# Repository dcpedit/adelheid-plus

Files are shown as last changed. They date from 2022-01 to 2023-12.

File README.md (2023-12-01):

# 𝕬𝖉𝖊𝖑𝖍𝖊𝖎𝖉 Plus

The Adelheid Plus is a fork of [Flookay's Adelheid case and PCB](https://github.com/floookay/adelheid).

adelheid_plus_resized
*Photo by yosoyjose*

Repository folders:

- `pcb`: KiCad files
- `pcb-mu`: KiCad files for Atmega32u4-MU chip (same pinout as Atmega32u4-AU, but smaller footprint)
- `case`: High profile case files
- `wrist-rest`: Wrist rest files

I modifed the pcb a bit to accept an Atmega32u4-MU since those seem to be in stock more often.

## Changes in this fork

- USB-C connector
- Option for 2U backspace
- Extra `B` key
- Option for rotary encoder at `F13` position
- Option for 2.25U left space + 1.25U modifier combo (requires modification to plate)

## Layout

[Keyboard-Layout-Editor](http://www.keyboard-layout-editor.com/#/gists/57b8a9ee4aeb89308701e20eda9b5dfc) 
layout

## Firmware

See my Vial fork for the [firmware files](https://github.com/dcpedit/vial-qmk-dev/tree/dcpedit/keyboards/dcpedit/adelheid_plus) on the [`dcpedit` branch](https://github.com/dcpedit/vial-qmk-dev/tree/dcpedit).  I opted for Vial since it allows you to program the rotary encoder through their GUI: https://get.vial.today/

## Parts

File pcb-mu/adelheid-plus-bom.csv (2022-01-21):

Comment | Designator | Footprint | LCSC
22pF | C1,C2 | Capacitors_SMD:C_0805_HandSoldering | C1804
10uF | C3 | Capacitors_SMD:C_0805_HandSoldering | C15850
1uF (±10%) | C4 | Capacitors_SMD:C_0805_HandSoldering | C28323
1uF | C5 | Capacitors_SMD:C_0805_HandSoldering | C28323
0.1uF | C6,C7,C8,C9 | Capacitors_SMD:C_0805_HandSoldering | C49678
D | D1,D2,D3,D4,D5,D6,D7,D8,D9,D10,D11,D12,D13,D14,D15,D16,D17,D18,D19,D20,D21,D22,D23,D24,D25,D26,D27,D28,D29,D30,D31,D32,D33,D34,D35,D36,D37,D38,D39,D40,D41,D42,D43,D44,D45,D46,D47,D48,D49,D50,D51,D52,D53,D54,D55,D56,D57,D58,D59,D60,D61,D62,D63,D64,D65,D66,D67,D68,D69,D70,D71,D72,D73,D74,D75,D76,D77,D78,D79,D80,D81,D82,D34_1 | Diode_SMD:D_SOD-123 | C81598
LED | LS1,LS2,LS3,LS4,LS5,LS6,LS7,LS8,LS9,LS10,LS11,LS12,LS13,LS14,LS15,LS16,LS17 | LED_SMD:LED_0805_2012Metric_Pad1.15x1.40mm_HandSolder | C34499
2N7002 | Q1 | Package_TO_SOT_SMD:SOT-23 | C8545
22 | R1,R2 | Resistor_SMD:R_0805_2012Metric_Pad1.15x1.40mm_HandSolder | C17561
10K | R3,R4 | Resistor_SMD:R_0805_2012Metric_Pad1.15x1.40mm_HandSolder | C17414
1.5K | R5 | Resistor_SMD:R_0805_2012Metric_Pad1.15x1.40mm_HandSolder | C4310
R | RL1,RS1,RL2,RS2,RL3,RS3,RL4,RS4,RL5,RS5,RL6,RS6,RL7,RS7,RL8,RS8,RL9,RS9,RL10,RS10,RL11,RS11,RL12,RS12,RL13,RS13,RL14,RS14,RL15,RS15,RL16,RS16,RL17,RS17,RL18,RL19,RL20,RL21,RL22,RL23,RL24,RL25,RL26,RL27,RL28,RL29,RL30,RL31,RL32,RL33,RL34,RL35,RL36,RL37,RL38,RL39,RL40,RL41,RL42,RL43,RL44,RL45,RL46,RL47,RL48,RL49,RL50,RL51,RL52,RL53,RL54,RL55,RL56,RL57,RL58,RL59,RL60,RL61,RL62,RL63,RL64,RL65,RL66,RL67,RL68,RL69,RL70,RL71,RL72,RL73,RL74,RL75,RL76,RL77,RL78,RL79,RL80,RL81,RL82 | Resistor_SMD:R_0805_2012Metric_Pad1.15x1.40mm_HandSolder | C17798
R | RL34_1 | Resistor_SMD:R_0805_2012Metric_Pad1.20x1.40mm_HandSolder | C17798
5.1K | RU1,RU2 | Resistor_SMD:R_0805_2012Metric_Pad1.20x1.40mm_HandSolder | C27834
ATmega32U4-MU | U2 | adelheid:QFN50P700X700X100-45N | C112161
Crystal_GND24 | Y1 | Crystals:Crystal_SMD_SeikoEpson_FA238-4pin_3.2x2.5mm_HandSoldering | C13738

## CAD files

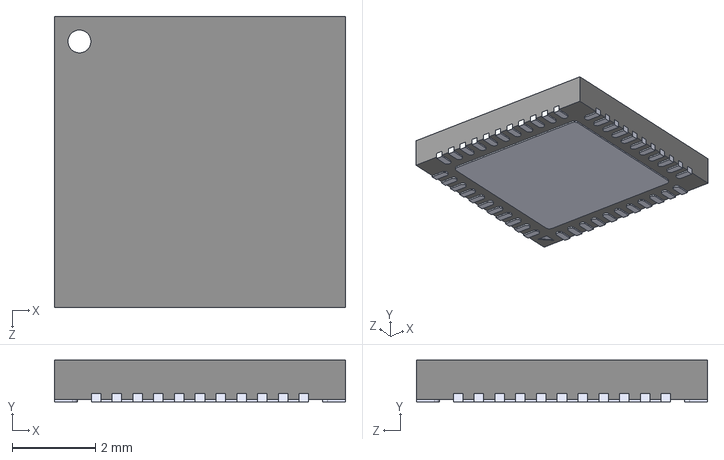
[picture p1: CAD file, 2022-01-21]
pcb-mu/ATMEGA32U4-MU.step
7.00 x 1.00 x 7.00 mm

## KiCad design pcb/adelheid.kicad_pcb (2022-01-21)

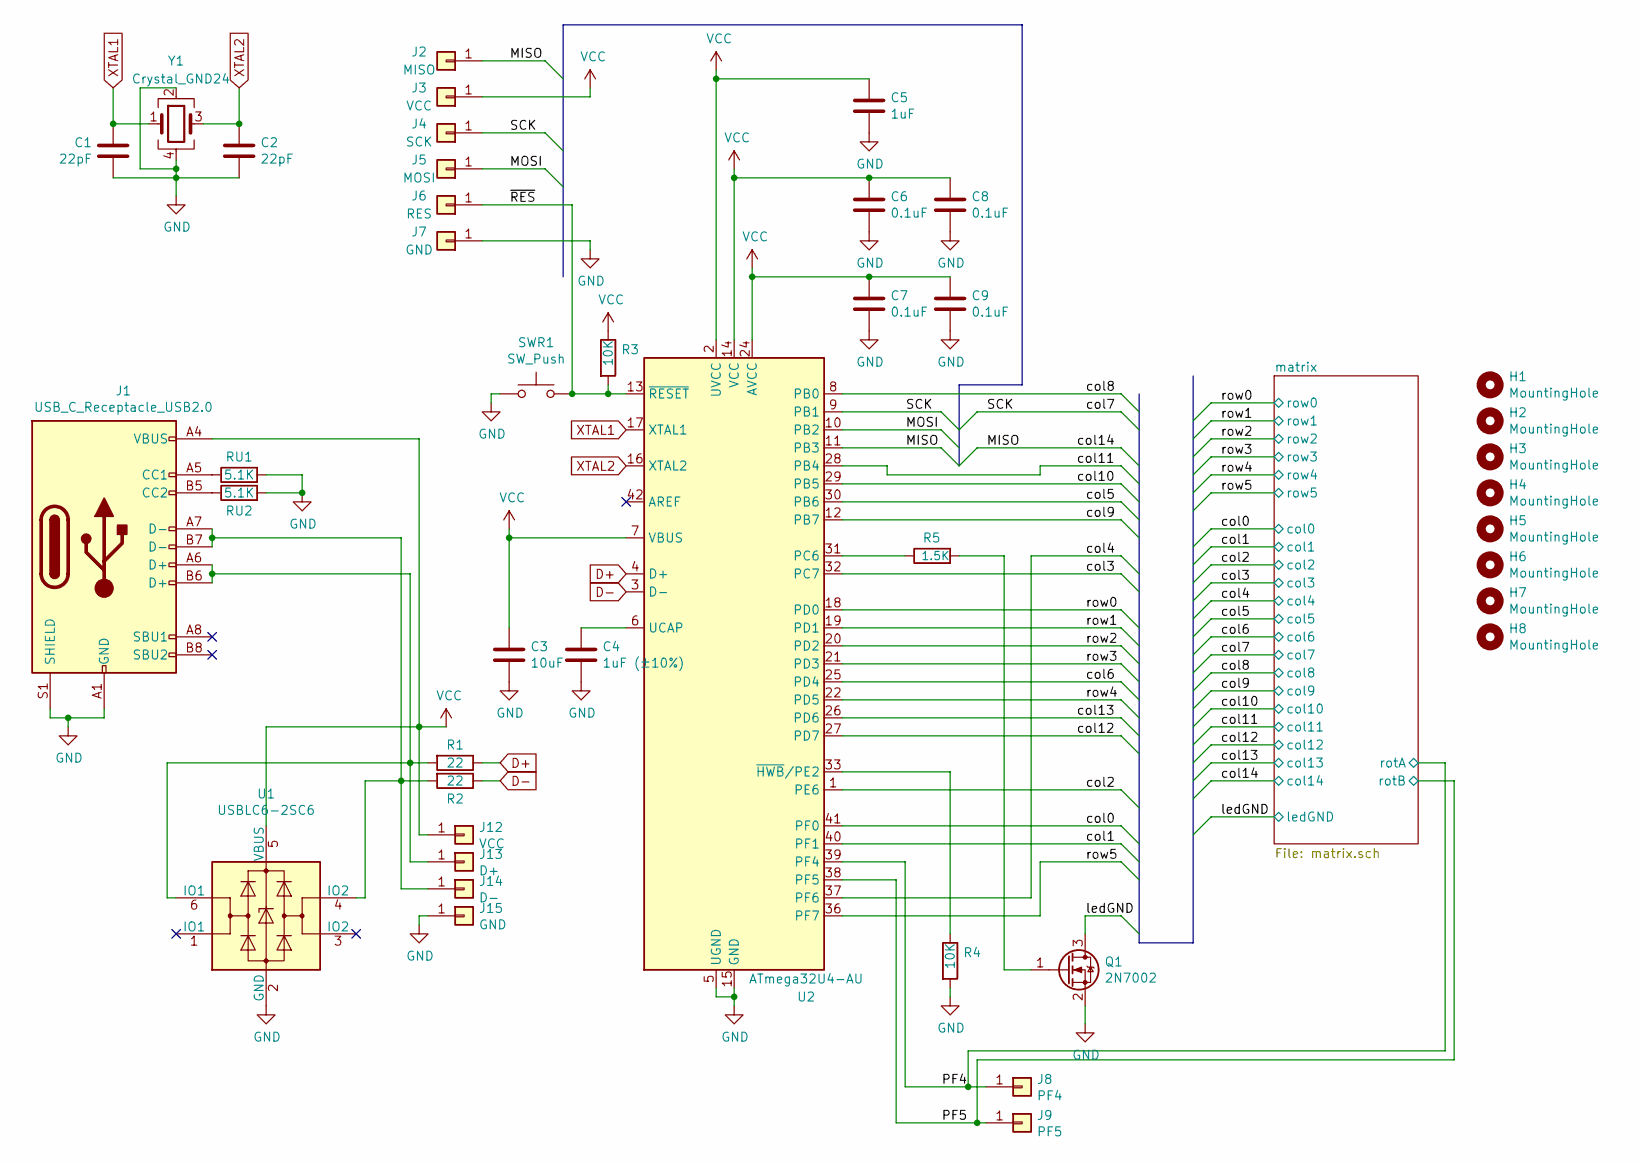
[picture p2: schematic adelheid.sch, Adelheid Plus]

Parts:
C1, C2: 22pF; C_0805_HandSoldering; LCSC C1804
C3: 10uF; C_0805_HandSoldering; LCSC C15850
C4: 1uF (±10%); C_0805_HandSoldering; LCSC C28323
C5: 1uF; C_0805_HandSoldering; LCSC C28323
C6, C7, C8, C9: 0.1uF; C_0805_HandSoldering; LCSC C49678
H1, H2, H3, H4, H5, H6, H7, H8: MountingHole; MountingHole_2.2mm_M2_Pad
J1: USB_C_Receptacle_USB2.0; USB_C_GCT_USB4085
J2: MISO; Pin_Header_Straight_1x01_Pitch2.54mm
J3, J12: VCC; Pin_Header_Straight_1x01_Pitch2.54mm
J4: SCK; Pin_Header_Straight_1x01_Pitch2.54mm
J5: MOSI; Pin_Header_Straight_1x01_Pitch2.54mm
J6: RES; Pin_Header_Straight_1x01_Pitch2.54mm
J7, J15: GND; Pin_Header_Straight_1x01_Pitch2.54mm
J8: PF4; Pin_Header_Straight_1x01_Pitch2.54mm
J9: PF5; Pin_Header_Straight_1x01_Pitch2.54mm
J13: D+; Pin_Header_Straight_1x01_Pitch2.54mm
J14: D-; Pin_Header_Straight_1x01_Pitch2.54mm
Q1: 2N7002; SOT-23; LCSC C8545
R1, R2: 22; R_0805_2012Metric_Pad1.15x1.40mm_HandSolder; LCSC C17561
R3, R4: 10K; R_0805_2012Metric_Pad1.15x1.40mm_HandSolder; LCSC C17414
R5: 1.5K; R_0805_2012Metric_Pad1.15x1.40mm_HandSolder; LCSC C4310
RU1, RU2: 5.1K; R_0805_2012Metric_Pad1.20x1.40mm_HandSolder; LCSC C27834
SWR1: SW_Push; SW_SPST_TL3342
U1: USBLC6-2SC6; SOT-23-6_Handsoldering; LCSC C7519
U2: ATmega32U4-AU; TQFP-44_10x10mm_Pitch0.8mm; LCSC C44854
Y1: Crystal_GND24; Crystal_SMD_SeikoEpson_FA238-4pin_3.2x2.5mm_HandSoldering; LCSC C13738

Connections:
/MISO: J2.1, U2.11 (PB3); also elsewhere on the board
/MOSI: J5.1, U2.10 (PB2)
/PF4: J8.1, U2.39 (PF4); also elsewhere on the board
/PF5: J9.1, U2.38 (PF5); also elsewhere on the board
/SCK: J4.1, U2.9 (PB1); also elsewhere on the board
/col0: U2.41 (PF0); also elsewhere on the board
/col1: U2.40 (PF1); also elsewhere on the board
/col2: U2.1 (PE6); also elsewhere on the board
/col3: U2.32 (PC7); also elsewhere on the board
/col4: U2.37 (PF6); also elsewhere on the board
/col5: U2.30 (PB6); also elsewhere on the board
/col6: U2.25 (PD4); also elsewhere on the board
/col8: U2.8 (PB0); also elsewhere on the board
/col9: U2.12 (PB7); also elsewhere on the board
/col10: U2.29 (PB5); also elsewhere on the board
/col11: U2.28 (PB4); also elsewhere on the board
/col12: U2.27 (PD7); also elsewhere on the board
/col13: U2.26 (PD6); also elsewhere on the board
/ledGND: Q1.3 (D); also elsewhere on the board
/row0: U2.18 (PD0); also elsewhere on the board
/row1: U2.19 (PD1); also elsewhere on the board
/row2: U2.20 (PD2); also elsewhere on the board
/row3: U2.21 (PD3); also elsewhere on the board
/row4: U2.22 (PD5); also elsewhere on the board
/row5: U2.36 (PF7); also elsewhere on the board
/~RES~: J6.1, R3.2, SWR1.2, U2.13 (~RESET)
D+: R1.1, U2.4 (D+)
D-: R2.1, U2.3 (D-)
GND: C1.1, C2.2, C3.2, C4.2, C5.2, C6.2, C7.2, C8.2, C9.2, J1.A1 (GND), J1.A12 (GND), J1.B1 (GND), J1.B12 (GND), J1.S1 (SHIELD), J7.1, J15.1, Q1.2 (S), R4.2, RU1.2, RU2.2, SWR1.1, U1.2 (GND), U2.5 (UGND), U2.15 (GND), U2.23 (GND), U2.35 (GND), U2.43 (GND), Y1.2, Y1.4; also elsewhere on the board
unnamed: C4.1, U2.6 (UCAP)
unnamed: J1.A5 (CC1), RU1.1
unnamed: J1.A6 (D+), J1.B6 (D+), J13.1, R1.2, U1.6 (IO1)
unnamed: J1.A7 (D-), J1.B7 (D-), J14.1, R2.2, U1.4 (IO2)
unnamed: J1.B5 (CC2), RU2.1
unnamed: Q1.1 (G), R5.2
unnamed: R4.1, U2.33 (~HWB~/PE2)
unnamed: R5.1, U2.31 (PC6)
VCC: C3.1, C5.1, C6.1, C7.1, C8.1, C9.1, J1.A4 (VBUS), J1.A9 (VBUS), J1.B4 (VBUS), J1.B9 (VBUS), J3.1, J12.1, R3.1, U1.5 (VBUS), U2.2 (UVCC), U2.7 (VBUS), U2.14 (VCC), U2.24 (AVCC), U2.34 (VCC), U2.44 (AVCC); also elsewhere on the board
XTAL1: C1.2, U2.17 (XTAL1), Y1.1
XTAL2: C2.1, U2.16 (XTAL2), Y1.3

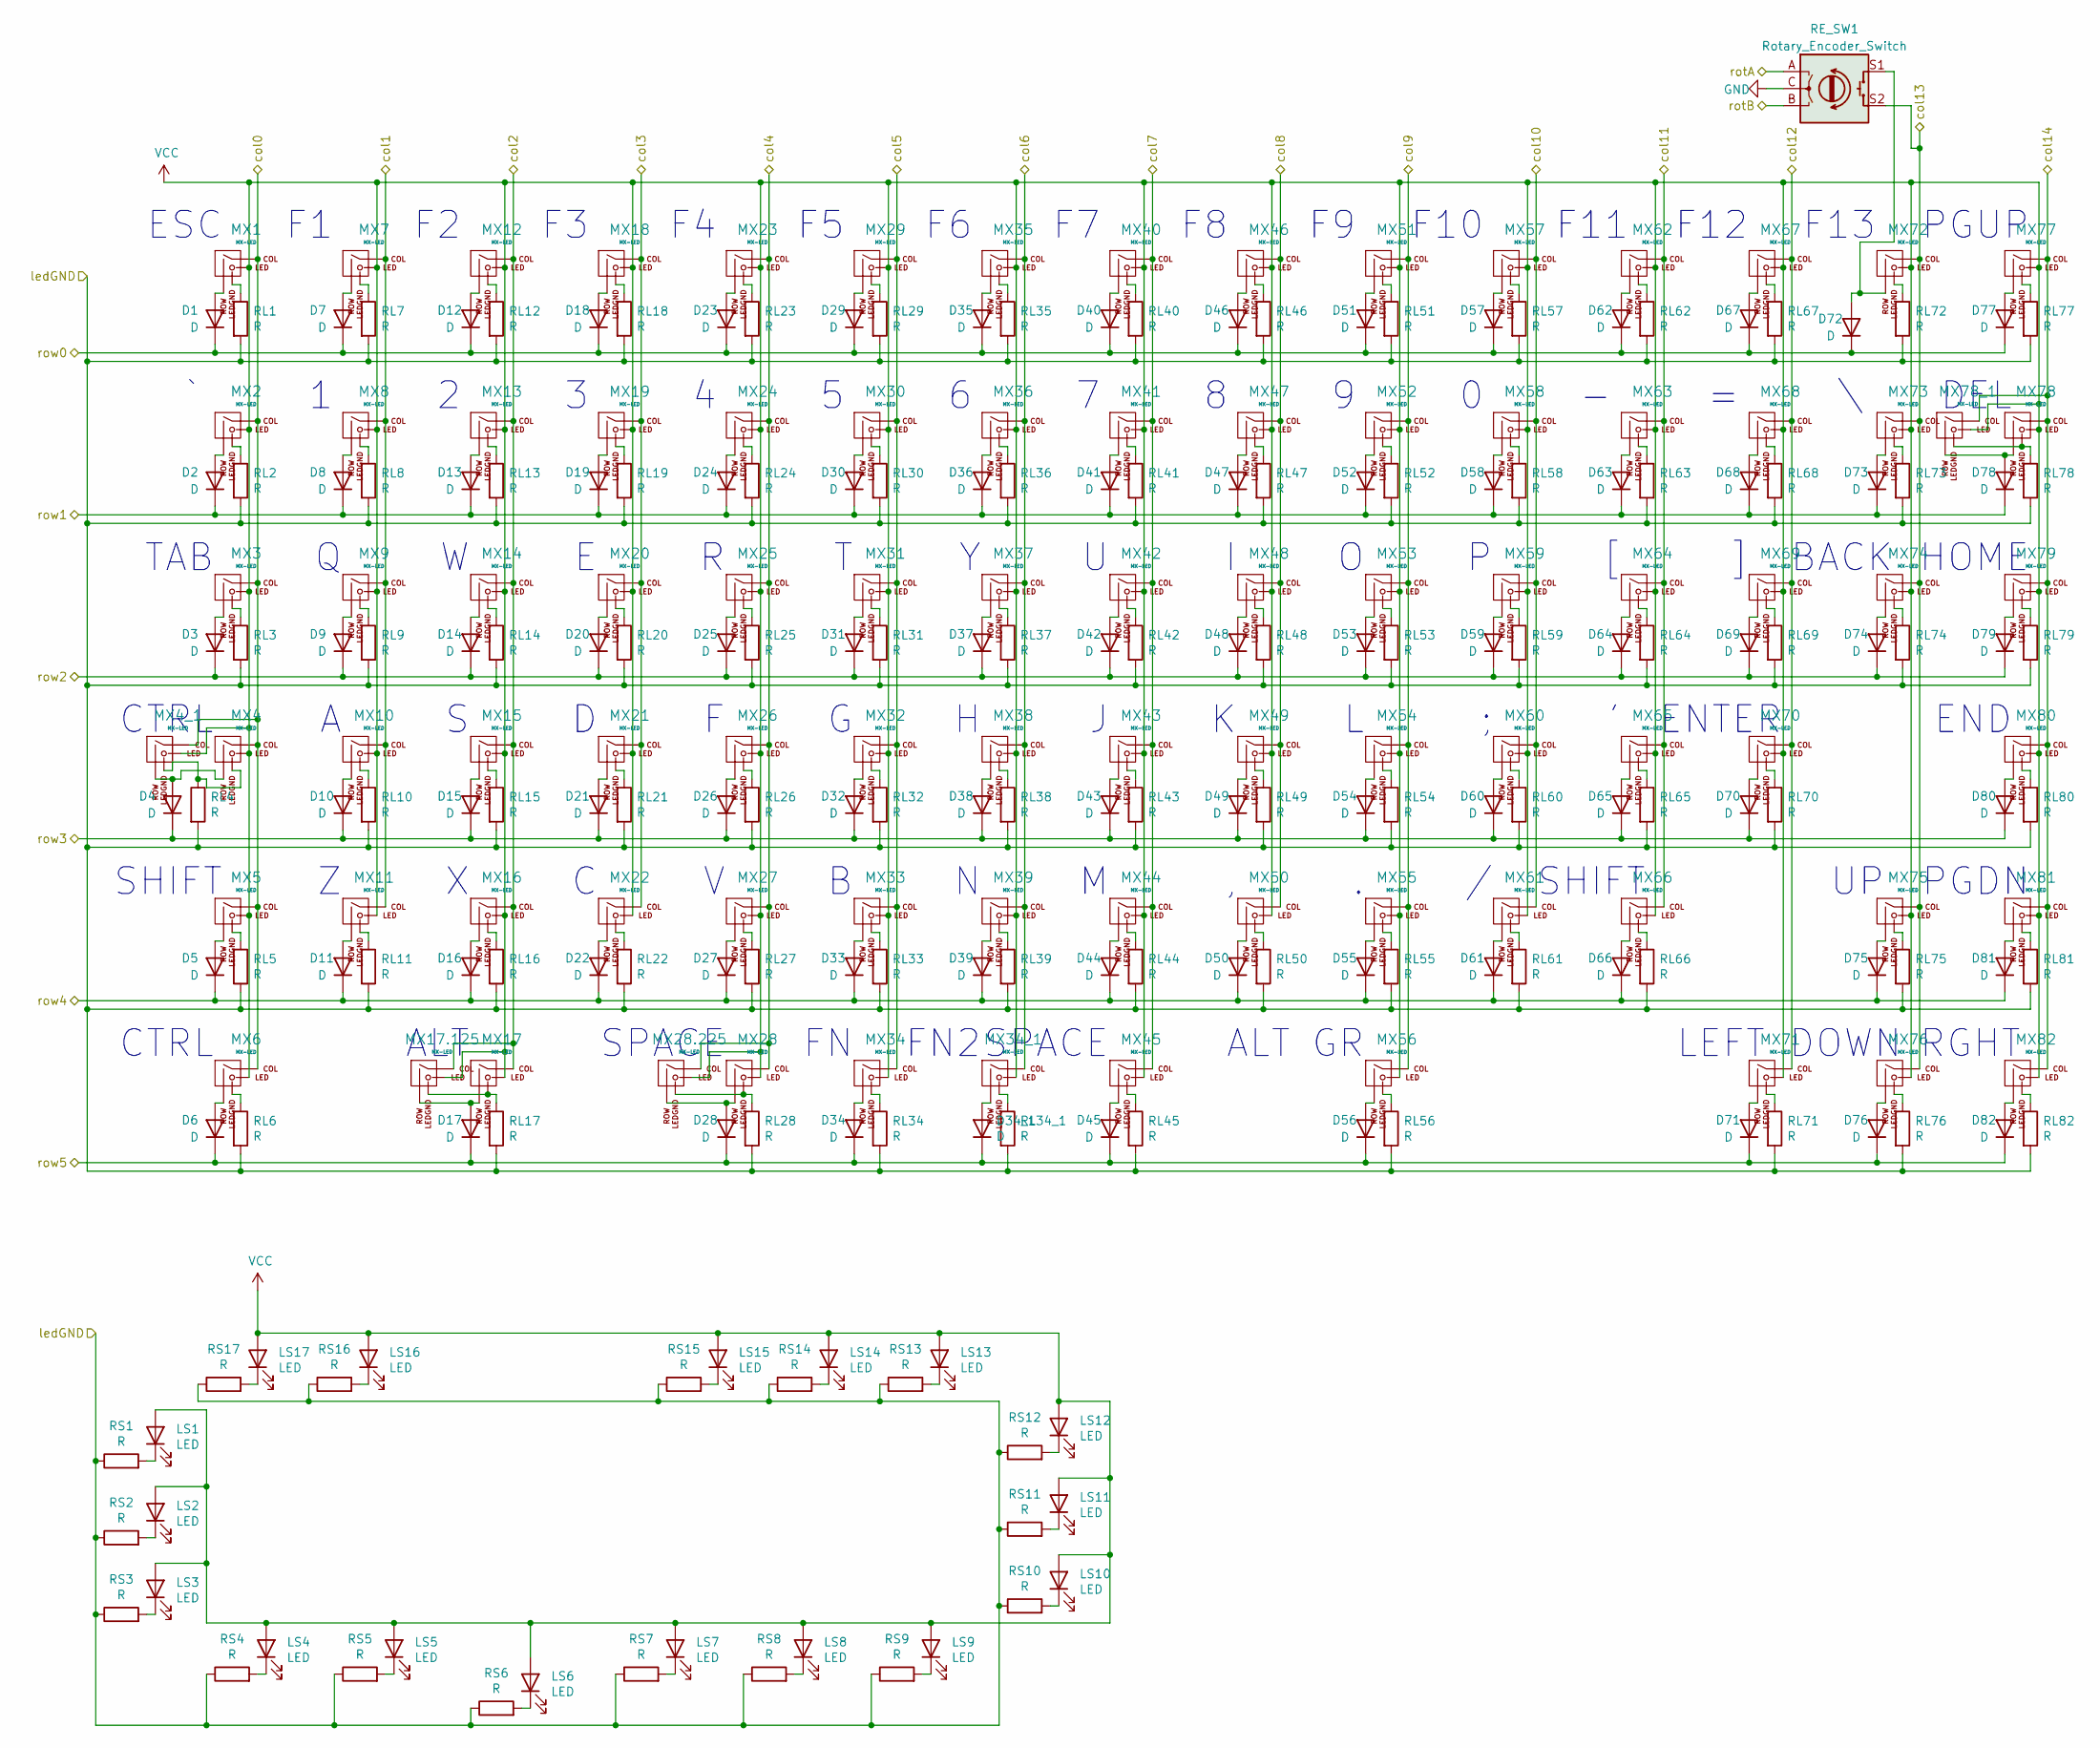
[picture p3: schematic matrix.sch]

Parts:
D1, D2, D3, D4, D5, D6, D7, D8, D9, D10, D11, D12, D13, D14, D15, D16, D17, D18, D19, D20, D21, D22, D23, D24, D25, D26, D27, D28, D29, D30, D31, D32, D33, D34, D34_1, D35, D36, D37, D38, D39, D40, D41, D42, D43, D44, D45, D46, D47, D48, D49, D50, D51, D52, D53, D54, D55, D56, D57, D58, D59, D60, D61, D62, D63, D64, D65, D66, D67, D68, D69, D70, D71, D72, D73, D74, D75, D76, D77, D78, D79, D80, D81, D82: D; D_SOD-123
LS1, LS2, LS3, LS4, LS5, LS6, LS7, LS8, LS9, LS10, LS11, LS12, LS13, LS14, LS15, LS16, LS17: LED; LED_0805_2012Metric_Pad1.15x1.40mm_HandSolder
MX1, MX2, MX7, MX8, MX9, MX10, MX11, MX12, MX13, MX14, MX15, MX16, MX18, MX19, MX20, MX21, MX22, MX23, MX24, MX25, MX26, MX27, MX29, MX30, MX31, MX32, MX33, MX34, MX34_1, MX35, MX36, MX37, MX38, MX39, MX40, MX41, MX42, MX43, MX44, MX46, MX47, MX48, MX49, MX50, MX51, MX52, MX53, MX54, MX55, MX57, MX58, MX59, MX60, MX61, MX62, MX63, MX64, MX65, MX67, MX68, MX69, MX71, MX72, MX73, MX75, MX76, MX77, MX78, MX79, MX80, MX81, MX82: MX-LED; MXOnly-1U
MX3, MX6, MX17, MX56, MX74: MX-LED; MXOnly-1.5U
MX4, MX66: MX-LED; MXOnly-1.75U
MX4_1: MX-LED; MXOnly-1.75U-FLIPPED
MX5: MX-LED; MXOnly-2.25U
MX17.125: MX-LED; MXOnly-1.25U
MX28: MX-LED; MXOnly-2U-ReversedStabilizers
MX28.225, MX70: MX-LED; MXOnly-2.25U-ReversedStabilizers
MX45: MX-LED; MXOnly-2.75U-ReversedStabilizers
MX78_1: MX-LED; MXOnly-2U
RE_SW1: Rotary_Encoder_Switch; RotaryEncoder_EC11
RL1, RL2, RL3, RL4, RL5, RL6, RL7, RL8, RL9, RL10, RL11, RL12, RL13, RL14, RL15, RL16, RL17, RL18, RL19, RL20, RL21, RL22, RL23, RL24, RL25, RL26, RL27, RL28, RL29, RL30, RL31, RL32, RL33, RL34, RL35, RL36, RL37, RL38, RL39, RL40, RL41, RL42, RL43, RL44, RL45, RL46, RL47, RL48, RL49, RL50, RL51, RL52, RL53, RL54, RL55, RL56, RL57, RL58, RL59, RL60, RL61, RL62, RL63, RL64, RL65, RL66, RL67, RL68, RL69, RL70, RL71, RL72, RL73, RL74, RL75, RL76, RL77, RL78, RL79, RL80, RL81, RL82: R; R_0805_2012Metric_Pad1.15x1.40mm_HandSolder
RL34_1: R; R_0805_2012Metric_Pad1.20x1.40mm_HandSolder; LCSC C17798
RS1, RS2, RS3, RS4, RS5, RS6, RS7, RS8, RS9, RS10, RS11, RS12, RS13, RS14, RS15, RS16, RS17: R; R_0805_2012Metric_Pad1.15x1.40mm_HandSolder

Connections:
/MISO: MX77.1 (COL), MX78.1 (COL), MX78_1.1 (COL), MX79.1 (COL), MX80.1 (COL), MX81.1 (COL), MX82.1 (COL); also elsewhere on the board
/PF4: RE_SW1.A; also elsewhere on the board
/PF5: RE_SW1.B; also elsewhere on the board
/SCK: MX40.1 (COL), MX41.1 (COL), MX42.1 (COL), MX43.1 (COL), MX44.1 (COL), MX45.1 (COL); also elsewhere on the board
/col0: MX1.1 (COL), MX2.1 (COL), MX3.1 (COL), MX4.1 (COL), MX4_1.1 (COL), MX5.1 (COL), MX6.1 (COL); also elsewhere on the board
/col1: MX7.1 (COL), MX8.1 (COL), MX9.1 (COL), MX10.1 (COL), MX11.1 (COL); also elsewhere on the board
/col2: MX12.1 (COL), MX13.1 (COL), MX14.1 (COL), MX15.1 (COL), MX16.1 (COL), MX17.1 (COL), MX17.125.1 (COL); also elsewhere on the board
/col3: MX18.1 (COL), MX19.1 (COL), MX20.1 (COL), MX21.1 (COL), MX22.1 (COL); also elsewhere on the board
/col4: MX23.1 (COL), MX24.1 (COL), MX25.1 (COL), MX26.1 (COL), MX27.1 (COL), MX28.1 (COL), MX28.225.1 (COL); also elsewhere on the board
/col5: MX29.1 (COL), MX30.1 (COL), MX31.1 (COL), MX32.1 (COL), MX33.1 (COL), MX34.1 (COL); also elsewhere on the board
/col6: MX34_1.1 (COL), MX35.1 (COL), MX36.1 (COL), MX37.1 (COL), MX38.1 (COL), MX39.1 (COL); also elsewhere on the board
/col8: MX46.1 (COL), MX47.1 (COL), MX48.1 (COL), MX49.1 (COL), MX50.1 (COL); also elsewhere on the board
/col9: MX51.1 (COL), MX52.1 (COL), MX53.1 (COL), MX54.1 (COL), MX55.1 (COL), MX56.1 (COL); also elsewhere on the board
/col10: MX57.1 (COL), MX58.1 (COL), MX59.1 (COL), MX60.1 (COL), MX61.1 (COL); also elsewhere on the board
/col11: MX62.1 (COL), MX63.1 (COL), MX64.1 (COL), MX65.1 (COL), MX66.1 (COL); also elsewhere on the board
/col12: MX67.1 (COL), MX68.1 (COL), MX69.1 (COL), MX70.1 (COL), MX71.1 (COL); also elsewhere on the board
/col13: MX72.1 (COL), MX73.1 (COL), MX74.1 (COL), MX75.1 (COL), MX76.1 (COL), RE_SW1.S2; also elsewhere on the board
/ledGND: RL1.2, RL2.2, RL3.2, RL4.2, RL5.2, RL6.2, RL7.2, RL8.2, RL9.2, RL10.2, RL11.2, RL12.2, RL13.2, RL14.2, RL15.2, RL16.2, RL17.2, RL18.2, RL19.2, RL20.2, RL21.2, RL22.2, RL23.2, RL24.2, RL25.2, RL26.2, RL27.2, RL28.2, RL29.2, RL30.2, RL31.2, RL32.2, RL33.2, RL34.2, RL34_1.2, RL35.2, RL36.2, RL37.2, RL38.2, RL39.2, RL40.2, RL41.2, RL42.2, RL43.2, RL44.2, RL45.2, RL46.2, RL47.2, RL48.2, RL49.2, RL50.2, RL51.2, RL52.2, RL53.2, RL54.2, RL55.2, RL56.2, RL57.2, RL58.2, RL59.2, RL60.2, RL61.2, RL62.2, RL63.2, RL64.2, RL65.2, RL66.2, RL67.2, RL68.2, RL69.2, RL70.2, RL71.2, RL72.2, RL73.2, RL74.2, RL75.2, RL76.2, RL77.2, RL78.2, RL79.2, RL80.2, RL81.2, RL82.2, RS1.1, RS2.1, RS3.1, RS4.1, RS5.1, RS6.1, RS7.1, RS8.1, RS9.1, RS10.1, RS11.1, RS12.1, RS13.1, RS14.1, RS15.1, RS16.1, RS17.1; also elsewhere on the board
/row0: D1.1 (K), D7.1 (K), D12.1 (K), D18.1 (K), D23.1 (K), D29.1 (K), D35.1 (K), D40.1 (K), D46.1 (K), D51.1 (K), D57.1 (K), D62.1 (K), D67.1 (K), D72.1 (K), D77.1 (K); also elsewhere on the board
/row1: D2.1 (K), D8.1 (K), D13.1 (K), D19.1 (K), D24.1 (K), D30.1 (K), D36.1 (K), D41.1 (K), D47.1 (K), D52.1 (K), D58.1 (K), D63.1 (K), D68.1 (K), D73.1 (K), D78.1 (K); also elsewhere on the board
/row2: D3.1 (K), D9.1 (K), D14.1 (K), D20.1 (K), D25.1 (K), D31.1 (K), D37.1 (K), D42.1 (K), D48.1 (K), D53.1 (K), D59.1 (K), D64.1 (K), D69.1 (K), D74.1 (K), D79.1 (K); also elsewhere on the board
/row3: D4.1 (K), D10.1 (K), D15.1 (K), D21.1 (K), D26.1 (K), D32.1 (K), D38.1 (K), D43.1 (K), D49.1 (K), D54.1 (K), D60.1 (K), D65.1 (K), D70.1 (K), D80.1 (K); also elsewhere on the board
/row4: D5.1 (K), D11.1 (K), D16.1 (K), D22.1 (K), D27.1 (K), D33.1 (K), D39.1 (K), D44.1 (K), D50.1 (K), D55.1 (K), D61.1 (K), D66.1 (K), D75.1 (K), D81.1 (K); also elsewhere on the board
/row5: D6.1 (K), D17.1 (K), D28.1 (K), D34.1 (K), D34_1.1 (K), D45.1 (K), D56.1 (K), D71.1 (K), D76.1 (K), D82.1 (K); also elsewhere on the board
GND: RE_SW1.C; also elsewhere on the board
unnamed: D1.2 (A), MX1.2 (ROW)
unnamed: D2.2 (A), MX2.2 (ROW)
unnamed: D3.2 (A), MX3.2 (ROW)
unnamed: D4.2 (A), MX4.2 (ROW), MX4_1.2 (ROW)
unnamed: D5.2 (A), MX5.2 (ROW)
unnamed: D6.2 (A), MX6.2 (ROW)
unnamed: D7.2 (A), MX7.2 (ROW)
unnamed: D8.2 (A), MX8.2 (ROW)
unnamed: D9.2 (A), MX9.2 (ROW)
unnamed: D10.2 (A), MX10.2 (ROW)
unnamed: D11.2 (A), MX11.2 (ROW)
unnamed: D12.2 (A), MX12.2 (ROW)
unnamed: D13.2 (A), MX13.2 (ROW)
unnamed: D14.2 (A), MX14.2 (ROW)
unnamed: D15.2 (A), MX15.2 (ROW)
unnamed: D16.2 (A), MX16.2 (ROW)
unnamed: D17.2 (A), MX17.2 (ROW), MX17.125.2 (ROW)
unnamed: D18.2 (A), MX18.2 (ROW)
unnamed: D19.2 (A), MX19.2 (ROW)
unnamed: D20.2 (A), MX20.2 (ROW)
unnamed: D21.2 (A), MX21.2 (ROW)
unnamed: D22.2 (A), MX22.2 (ROW)
unnamed: D23.2 (A), MX23.2 (ROW)
unnamed: D24.2 (A), MX24.2 (ROW)
unnamed: D25.2 (A), MX25.2 (ROW)
unnamed: D26.2 (A), MX26.2 (ROW)
unnamed: D27.2 (A), MX27.2 (ROW)
unnamed: D28.2 (A), MX28.2 (ROW), MX28.225.2 (ROW)
unnamed: D29.2 (A), MX29.2 (ROW)
unnamed: D30.2 (A), MX30.2 (ROW)
unnamed: D31.2 (A), MX31.2 (ROW)
unnamed: D32.2 (A), MX32.2 (ROW)
unnamed: D33.2 (A), MX33.2 (ROW)
unnamed: D34.2 (A), MX34.2 (ROW)
unnamed: D34_1.2 (A), MX34_1.2 (ROW)
unnamed: D35.2 (A), MX35.2 (ROW)
unnamed: D36.2 (A), MX36.2 (ROW)
unnamed: D37.2 (A), MX37.2 (ROW)
unnamed: D38.2 (A), MX38.2 (ROW)
unnamed: D39.2 (A), MX39.2 (ROW)
unnamed: D40.2 (A), MX40.2 (ROW)
unnamed: D41.2 (A), MX41.2 (ROW)
unnamed: D42.2 (A), MX42.2 (ROW)
unnamed: D43.2 (A), MX43.2 (ROW)
unnamed: D44.2 (A), MX44.2 (ROW)
unnamed: D45.2 (A), MX45.2 (ROW)
unnamed: D46.2 (A), MX46.2 (ROW)
unnamed: D47.2 (A), MX47.2 (ROW)
unnamed: D48.2 (A), MX48.2 (ROW)
unnamed: D49.2 (A), MX49.2 (ROW)
unnamed: D50.2 (A), MX50.2 (ROW)
unnamed: D51.2 (A), MX51.2 (ROW)
unnamed: D52.2 (A), MX52.2 (ROW)
unnamed: D53.2 (A), MX53.2 (ROW)
unnamed: D54.2 (A), MX54.2 (ROW)
unnamed: D55.2 (A), MX55.2 (ROW)
unnamed: D56.2 (A), MX56.2 (ROW)
unnamed: D57.2 (A), MX57.2 (ROW)
unnamed: D58.2 (A), MX58.2 (ROW)
unnamed: D59.2 (A), MX59.2 (ROW)
unnamed: D60.2 (A), MX60.2 (ROW)
unnamed: D61.2 (A), MX61.2 (ROW)
unnamed: D62.2 (A), MX62.2 (ROW)
unnamed: D63.2 (A), MX63.2 (ROW)
unnamed: D64.2 (A), MX64.2 (ROW)
unnamed: D65.2 (A), MX65.2 (ROW)
unnamed: D66.2 (A), MX66.2 (ROW)
unnamed: D67.2 (A), MX67.2 (ROW)
unnamed: D68.2 (A), MX68.2 (ROW)
unnamed: D69.2 (A), MX69.2 (ROW)
unnamed: D70.2 (A), MX70.2 (ROW)
unnamed: D71.2 (A), MX71.2 (ROW)
unnamed: D72.2 (A), MX72.2 (ROW), RE_SW1.S1
unnamed: D73.2 (A), MX73.2 (ROW)
unnamed: D74.2 (A), MX74.2 (ROW)
unnamed: D75.2 (A), MX75.2 (ROW)
unnamed: D76.2 (A), MX76.2 (ROW)
unnamed: D77.2 (A), MX77.2 (ROW)
unnamed: D78.2 (A), MX78.2 (ROW), MX78_1.2 (ROW)
unnamed: D79.2 (A), MX79.2 (ROW)
unnamed: D80.2 (A), MX80.2 (ROW)
unnamed: D81.2 (A), MX81.2 (ROW)
unnamed: D82.2 (A), MX82.2 (ROW)
unnamed: LS1.1 (K), RS1.2
unnamed: LS2.1 (K), RS2.2
unnamed: LS3.1 (K), RS3.2
unnamed: LS4.1 (K), RS4.2
unnamed: LS5.1 (K), RS5.2
unnamed: LS6.1 (K), RS6.2
unnamed: LS7.1 (K), RS7.2
unnamed: LS8.1 (K), RS8.2
unnamed: LS9.1 (K), RS9.2
unnamed: LS10.1 (K), RS10.2
unnamed: LS11.1 (K), RS11.2
unnamed: LS12.1 (K), RS12.2
unnamed: LS13.1 (K), RS13.2
unnamed: LS14.1 (K), RS14.2
unnamed: LS15.1 (K), RS15.2
unnamed: LS16.1 (K), RS16.2
unnamed: LS17.1 (K), RS17.2
unnamed: MX1.4 (LEDGND), RL1.1
unnamed: MX2.4 (LEDGND), RL2.1
unnamed: MX3.4 (LEDGND), RL3.1
unnamed: MX4.4 (LEDGND), MX4_1.4 (LEDGND), RL4.1
unnamed: MX5.4 (LEDGND), RL5.1
unnamed: MX6.4 (LEDGND), RL6.1
unnamed: MX7.4 (LEDGND), RL7.1
unnamed: MX8.4 (LEDGND), RL8.1
unnamed: MX9.4 (LEDGND), RL9.1
unnamed: MX10.4 (LEDGND), RL10.1
unnamed: MX11.4 (LEDGND), RL11.1
unnamed: MX12.4 (LEDGND), RL12.1
unnamed: MX13.4 (LEDGND), RL13.1
unnamed: MX14.4 (LEDGND), RL14.1
unnamed: MX15.4 (LEDGND), RL15.1
unnamed: MX16.4 (LEDGND), RL16.1
unnamed: MX17.4 (LEDGND), MX17.125.4 (LEDGND), RL17.1
unnamed: MX18.4 (LEDGND), RL18.1
unnamed: MX19.4 (LEDGND), RL19.1
unnamed: MX20.4 (LEDGND), RL20.1
unnamed: MX21.4 (LEDGND), RL21.1
unnamed: MX22.4 (LEDGND), RL22.1
unnamed: MX23.4 (LEDGND), RL23.1
unnamed: MX24.4 (LEDGND), RL24.1
unnamed: MX25.4 (LEDGND), RL25.1
unnamed: MX26.4 (LEDGND), RL26.1
unnamed: MX27.4 (LEDGND), RL27.1
unnamed: MX28.4 (LEDGND), MX28.225.4 (LEDGND), RL28.1
unnamed: MX29.4 (LEDGND), RL29.1
unnamed: MX30.4 (LEDGND), RL30.1
unnamed: MX31.4 (LEDGND), RL31.1
unnamed: MX32.4 (LEDGND), RL32.1
unnamed: MX33.4 (LEDGND), RL33.1
unnamed: MX34.4 (LEDGND), RL34.1
unnamed: MX34_1.4 (LEDGND), RL34_1.1
unnamed: MX35.4 (LEDGND), RL35.1
unnamed: MX36.4 (LEDGND), RL36.1
unnamed: MX37.4 (LEDGND), RL37.1
unnamed: MX38.4 (LEDGND), RL38.1
unnamed: MX39.4 (LEDGND), RL39.1
unnamed: MX40.4 (LEDGND), RL40.1
unnamed: MX41.4 (LEDGND), RL41.1
unnamed: MX42.4 (LEDGND), RL42.1
unnamed: MX43.4 (LEDGND), RL43.1
unnamed: MX44.4 (LEDGND), RL44.1
unnamed: MX45.4 (LEDGND), RL45.1
unnamed: MX46.4 (LEDGND), RL46.1
unnamed: MX47.4 (LEDGND), RL47.1
unnamed: MX48.4 (LEDGND), RL48.1
unnamed: MX49.4 (LEDGND), RL49.1
unnamed: MX50.4 (LEDGND), RL50.1
unnamed: MX51.4 (LEDGND), RL51.1
unnamed: MX52.4 (LEDGND), RL52.1
unnamed: MX53.4 (LEDGND), RL53.1
unnamed: MX54.4 (LEDGND), RL54.1
unnamed: MX55.4 (LEDGND), RL55.1
unnamed: MX56.4 (LEDGND), RL56.1
unnamed: MX57.4 (LEDGND), RL57.1
unnamed: MX58.4 (LEDGND), RL58.1
unnamed: MX59.4 (LEDGND), RL59.1
unnamed: MX60.4 (LEDGND), RL60.1
unnamed: MX61.4 (LEDGND), RL61.1
unnamed: MX62.4 (LEDGND), RL62.1
unnamed: MX63.4 (LEDGND), RL63.1
unnamed: MX64.4 (LEDGND), RL64.1
unnamed: MX65.4 (LEDGND), RL65.1
unnamed: MX66.4 (LEDGND), RL66.1
unnamed: MX67.4 (LEDGND), RL67.1
unnamed: MX68.4 (LEDGND), RL68.1
unnamed: MX69.4 (LEDGND), RL69.1
unnamed: MX70.4 (LEDGND), RL70.1
unnamed: MX71.4 (LEDGND), RL71.1
unnamed: MX72.4 (LEDGND), RL72.1
unnamed: MX73.4 (LEDGND), RL73.1
unnamed: MX74.4 (LEDGND), RL74.1
unnamed: MX75.4 (LEDGND), RL75.1
unnamed: MX76.4 (LEDGND), RL76.1
unnamed: MX77.4 (LEDGND), RL77.1
unnamed: MX78.4 (LEDGND), MX78_1.4 (LEDGND), RL78.1
unnamed: MX79.4 (LEDGND), RL79.1
unnamed: MX80.4 (LEDGND), RL80.1
unnamed: MX81.4 (LEDGND), RL81.1
unnamed: MX82.4 (LEDGND), RL82.1
VCC: LS1.2 (A), LS2.2 (A), LS3.2 (A), LS4.2 (A), LS5.2 (A), LS6.2 (A), LS7.2 (A), LS8.2 (A), LS9.2 (A), LS10.2 (A), LS11.2 (A), LS12.2 (A), LS13.2 (A), LS14.2 (A), LS15.2 (A), LS16.2 (A), LS17.2 (A), MX1.3 (LED), MX2.3 (LED), MX3.3 (LED), MX4.3 (LED), MX4_1.3 (LED), MX5.3 (LED), MX6.3 (LED), MX7.3 (LED), MX8.3 (LED), MX9.3 (LED), MX10.3 (LED), MX11.3 (LED), MX12.3 (LED), MX13.3 (LED), MX14.3 (LED), MX15.3 (LED), MX16.3 (LED), MX17.3 (LED), MX17.125.3 (LED), MX18.3 (LED), MX19.3 (LED), MX20.3 (LED), MX21.3 (LED), MX22.3 (LED), MX23.3 (LED), MX24.3 (LED), MX25.3 (LED), MX26.3 (LED), MX27.3 (LED), MX28.3 (LED), MX28.225.3 (LED), MX29.3 (LED), MX30.3 (LED), MX31.3 (LED), MX32.3 (LED), MX33.3 (LED), MX34.3 (LED), MX34_1.3 (LED), MX35.3 (LED), MX36.3 (LED), MX37.3 (LED), MX38.3 (LED), MX39.3 (LED), MX40.3 (LED), MX41.3 (LED), MX42.3 (LED), MX43.3 (LED), MX44.3 (LED), MX45.3 (LED), MX46.3 (LED), MX47.3 (LED), MX48.3 (LED), MX49.3 (LED), MX50.3 (LED), MX51.3 (LED), MX52.3 (LED), MX53.3 (LED), MX54.3 (LED), MX55.3 (LED), MX56.3 (LED), MX57.3 (LED), MX58.3 (LED), MX59.3 (LED), MX60.3 (LED), MX61.3 (LED), MX62.3 (LED), MX63.3 (LED), MX64.3 (LED), MX65.3 (LED), MX66.3 (LED), MX67.3 (LED), MX68.3 (LED), MX69.3 (LED), MX70.3 (LED), MX71.3 (LED), MX72.3 (LED), MX73.3 (LED), MX74.3 (LED), MX75.3 (LED), MX76.3 (LED), MX77.3 (LED), MX78.3 (LED), MX78_1.3 (LED), MX79.3 (LED), MX80.3 (LED), MX81.3 (LED), MX82.3 (LED); also elsewhere on the board

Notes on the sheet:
ESC
F10
F11
F12
F13
PGUP
DEL
HOME
END
PGDN
RGHT
DOWN
LEFT
TAB
BACK
CTRL
ENTER
SHIFT
ALT
SPACE
ALT GR
FN2

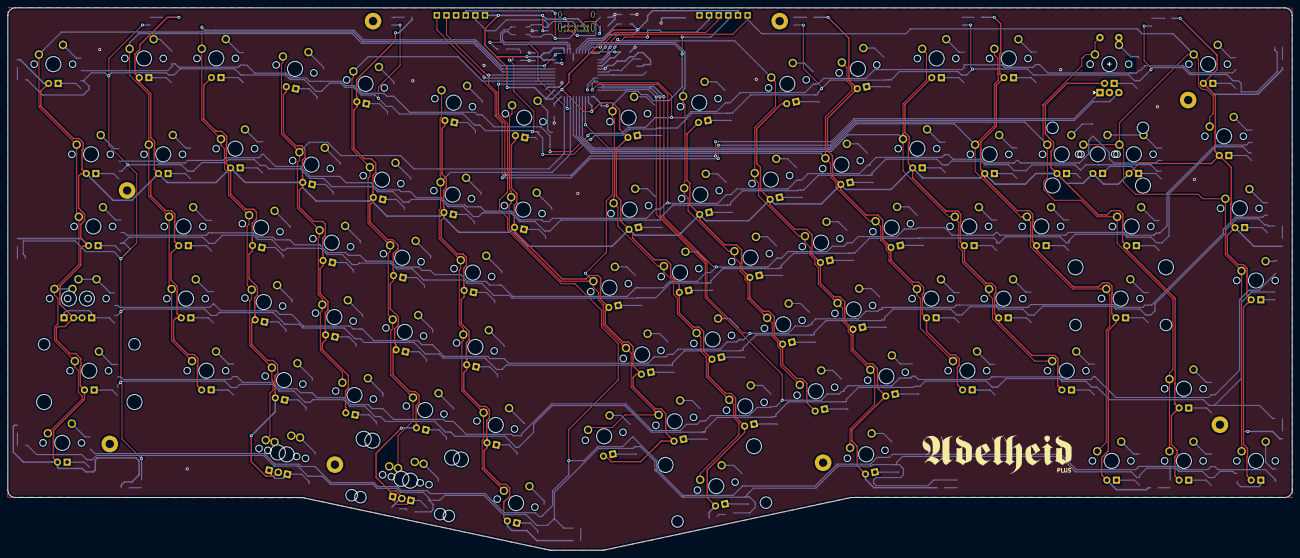
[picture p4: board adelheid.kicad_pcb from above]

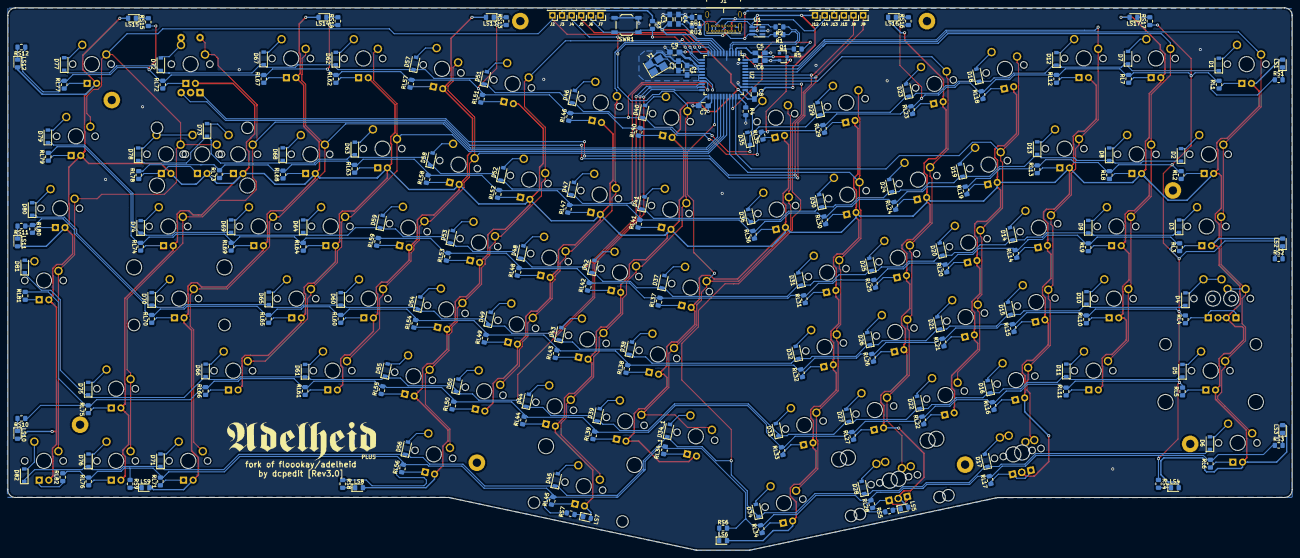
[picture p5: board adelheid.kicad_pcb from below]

Board: 2 copper layers, 339.1 x 143.2 mm, 332 parts (235 on the bottom side), 223 nets.

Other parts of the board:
 G2: LOGO; adelheid-logo
G1: LOGO; adelheid-logo

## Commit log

2022-01-21 Adelheid Plus keyboard files
    [ATMEGA32U4-MU.step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]
2022-01-27 Export svg dxf files
    [foam_bottom.dxf, foam_plate.dxf, plus_layers.dxf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]
2022-01-27 PCB readme
2022-04-09 Add firmware
    [foam_bottom.dxf, foam_plate.dxf, plus_layers.dxf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]
2023-12-01 Add block style case design
